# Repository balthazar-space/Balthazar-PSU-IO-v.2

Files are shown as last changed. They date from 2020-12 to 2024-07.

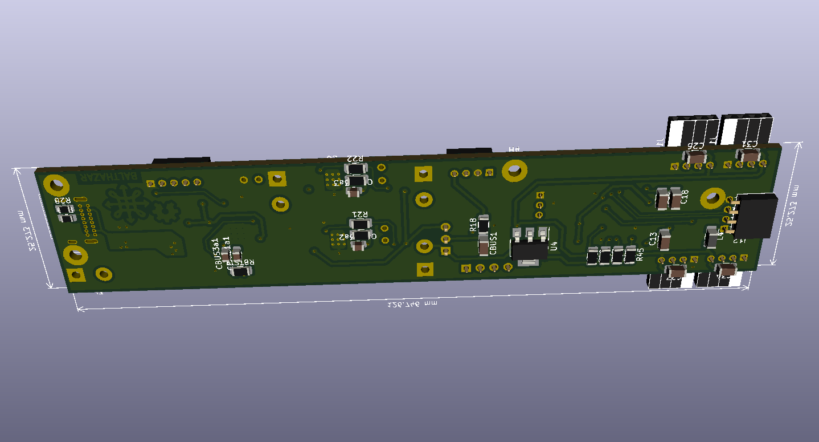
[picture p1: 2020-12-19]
images/BalthazarPSU2-4.png

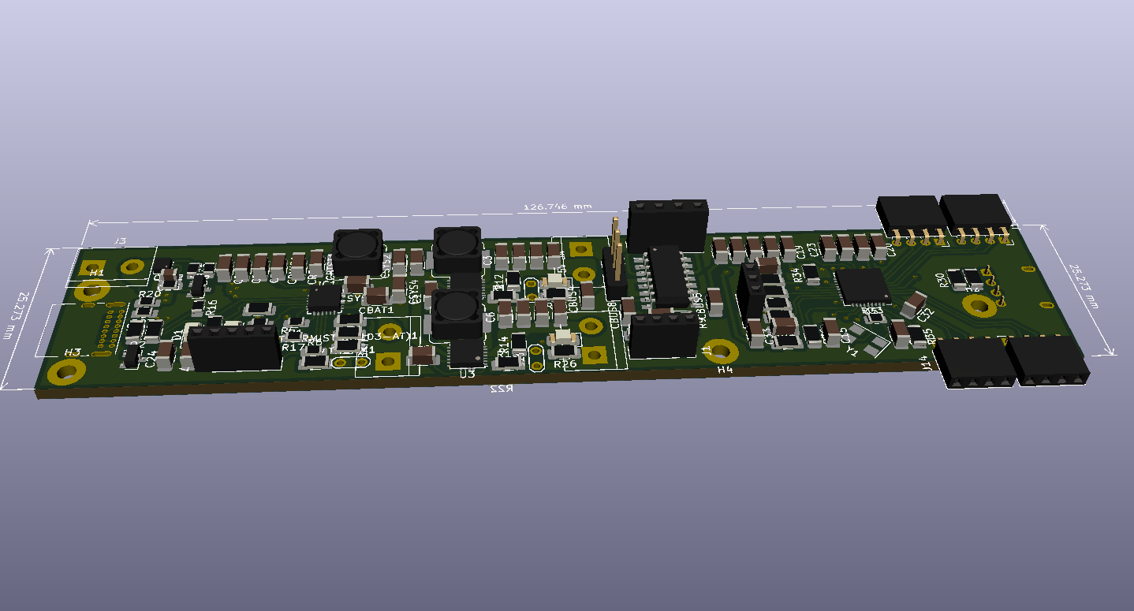
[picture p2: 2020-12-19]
images/BalthazarPSU2-2.png

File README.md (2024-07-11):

# Balthazar

Open-hardware laptop computer modules description and concept.

These are electronic schematic modules as presented at https://balthazar.space/wiki/Balthazar with the main aim for team access. See the [main repository](https://github.com/balthazar-space/balthazar) for other designs.

# balthazar PSU/IO v.2

Module BalthazarPSU2 is a combined battery charger, buck-boost coverter, stereo power amplifier and usb 2.0 hub. A somehow revised version of BalthazarPSU module, this one has an added usb 2.0 hub based on Microchip USB2514B which was much more readily available in Europe than GL3520 chip.
We also work on USB 3.0 - due to the chip shortage/availability - we now have to wait.

KiCad 5.1.5 files.

## License

All resources except the keyboard firmware - which is licensed with with GPLv3 or later - licensed under the CERN Open Hardware Licence CERN-OHL W V.2.0

Version 2.0 of the CERN-OHL introduces three variants of the licence – strongly (S) reciprocal, weakly (W) reciprocal and permissive (P) – which aim to address specific constraints caused by different collaboration models currently used in open-hardware projects. 

The first two variants mean that if any product is made using an open hardware design, the design of that product, including any improvements or modifications, should be made available under the same licence as that of the original product. Permissive licences do not impose this condition.

See the [LICENSE.md](./LICENSE.md) file for more information.

## Funding

This project is funded through the [NGI Zero Entrust Fund](https://nlnet.nl/entrust), a fund
established by [NLnet](https://nlnet.nl) with financial support from the European Commission's
[Next Generation Internet](https://ngi.eu) program. Learn more on the [NLnet project page](https://nlnet.nl/project/Balthazar-Casing/).

[NLNet foundation logo](https://nlnet.nl)
[NGI0 Entrust Logo](https://nlnet.nl/entrust)

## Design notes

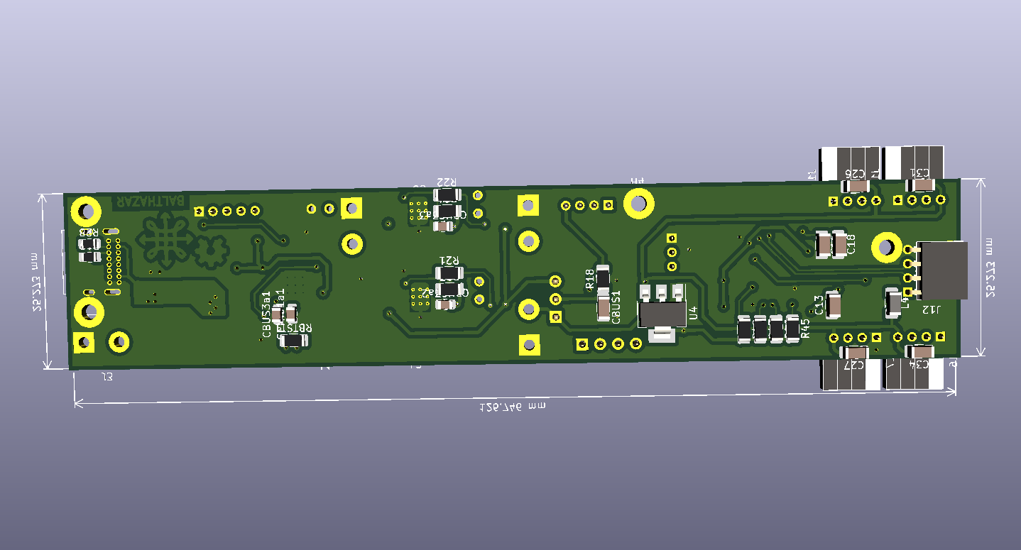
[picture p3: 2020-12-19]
images/BalthazarPSU2-5.png

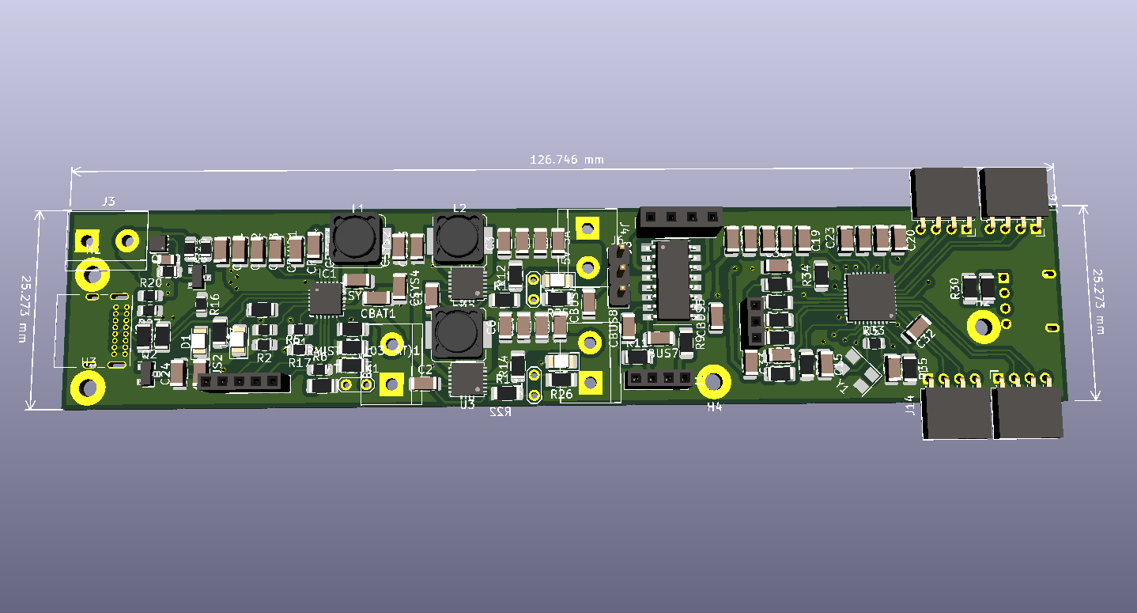
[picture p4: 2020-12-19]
images/BalthazarPSU2-1.png

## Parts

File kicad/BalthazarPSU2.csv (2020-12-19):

Id | Designator | Package | Quantity | Designation | Supplier and ref
1 | REF** | OSHW-Logo_Copper | 1 | OSHW-Logo_Copper
2 | G*** | BALTHAZARlogo150 | 1 | LOGO
3 | U2,U3 | WSON-14-1EP_4.0x4.0mm_P0.5mm_EP2.6x2.6mmThermalPads | 2 | TPS63020
4 | CPSU2,CPSU1,CBTST1,CBUS1,CBUS2,CBUS3,CBUS4,CBUS5,CBUS8,CREGN1,C16,C21 | C_1206_3216Metric | 12 | 1uF
5 | CSYS3,CSYS4,CBAT1,CPMID1,CSYS1,CSYS2,C12,C22,C29,C26,C27,C31,C34 | C_1206_3216Metric | 13 | 10uF
6 | R12,R14,R23,R24 | R_1206_3216Metric | 4 | 1M
7 | R13,R15 | R_1206_3216Metric | 2 | 180K
8 | RBTST1 | R_1206_3216Metric | 1 | R
9 | C8,C9,C3,C4,C10,C5,C7,C6 | C_1206_3216Metric | 8 | 22uF
10 | C1,C2,CBUS7,C11,C17,C18,C19,C23,C28,C30,C32,C33,C13,C20,C24 | C_1206_3216Metric | 15 | 0.1uF
11 | D1,D2,D4,D5 | LED_1206_3216Metric | 4 | Led
12 | R4,R5,R8,R9,R11,R21,R22 | R_1206_3216Metric | 7 | 2K2
13 | R7 | R_1206_3216Metric | 1 | 265
14 | R10 | R_1206_3216Metric | 1 | 6K8
15 | THERMISTOR(103-AT)1,R18,R43,R44,R45,R46,R47,R48 | R_1206_3216Metric | 8 | 10K
16 | IC1 | QFN-24-1EP_4x4mm_P0.5mm_EP2.7x2.7mm_ThermalVias | 1 | BQ24193
17 | U1 | SOP-16_4.4x10.4mm_P1.27mm | 1 | PAM8403-SOP16
18 | THERM1 | TestPoint_2Pads_Pitch2.54mm_Drill0.8mm | 1 | thermistor
19 | J10,J11 | TestPoint_2Pads_Pitch2.54mm_Drill0.8mm | 2 | 3.3V/5V
20 | R25,R26 | R_1206_3216Metric | 2 | 270K
21 | BATT1 | TerminalBlock_bornier-2_P5.08mm | 1 | 1s LiPo
22 | J8 | TerminalBlock_bornier-2_P5.08mm | 1 | 5V 3A
23 | J9 | TerminalBlock_bornier-2_P5.08mm | 1 | 3.3V 4A
24 | CBUS3a1,CBUS3a2,CBUS3a3,CPMID1a1 | C_0805_2012Metric | 4 | 0.1uF
25 | J2 | USB_C_Receptacle_GCT_USB4085 | 1 | USB_C_Receptacle_USB2.0
26 | L1 | L_Bourns_SRP7028A_7.3x6.6mm | 1 | 2.2uH 4A
27 | L2,L3 | L_Bourns_SRP7028A_7.3x6.6mm | 2 | 1.5uH 4A
28 | J3 | TerminalBlock_bornier-2_P5.08mm | 1 | 5-15V / 3-5A
29 | C14,C15 | C_1206_3216Metric | 2 | 20pF
30 | R29,R30,R31,R32,R34,R36,R37 | R_1206_3216Metric | 7 | 100K
31 | R35 | R_1206_3216Metric | 1 | 12K
32 | U4 | SOT-223-3_TabPin2 | 1 | AMS1117-3.3
33 | U5 | QFN-36-1EP_6x6mm_P0.5mm_EP3.7x3.7mm | 1 | USB2514B_Bi
34 | J13 | USB_Micro-B_Molex-Balthazar | 1 | USB_B_Micro
35 | R33 | R_0805_2012Metric | 1 | 1M
36 | C25 | C_0805_2012Metric | 1 | 1nF
37 | Q1 | Texas_DQK | 1 | CSD25310Q2
38 | Q2,Q3 | SOT-23 | 2 | BSS138
39 | R19,R27 | R_0805_2012Metric_Pad1.15x1.40mm_HandSolder | 2 | 5K1
40 | R20,R28 | R_0805_2012Metric_Pad1.15x1.40mm_HandSolder | 2 | 56K
41 | R40 | R_0805_2012Metric_Pad1.15x1.40mm_HandSolder | 1 | 262K
42 | R41 | R_0805_2012Metric_Pad1.15x1.40mm_HandSolder | 1 | 100K
43 | R42,R1,R2,R3,R6,R16,R17 | R_0805_2012Metric_Pad1.15x1.40mm_HandSolder | 7 | 10K
44 | J12,J14,J15,J16,J17 | PinSocket_1x04_P2.00mm_Horizontal | 5 | Conn_01x04_USB
45 | J4 | PinSocket_1x04_P2.54mm_Vertical | 1 | AudioOUT
46 | J7 | PinSocket_1x05_P2.00mm_Vertical | 1 | uC host / Atmel
47 | J1 | PinSocket_1x04_P2.00mm_Vertical | 1 | AudioIN
48 | R38 | R_1206_3216Metric | 1 | 120K
49 | R39 | R_1206_3216Metric | 1 | 49K9
50 | Y1 | Crystal_SMD_5032-4Pin_5.0x3.2mm | 1 | Crystal_GND24
51 | L4 | L_1206_3216Metric_Pad1.42x1.75mm_HandSolder | 1 | L_Core_Ferrite_Small
52 | J5 | PinSocket_1x03_P2.00mm_Vertical | 1 | uC host / Atmel
53 | J6 | PinHeader_1x03_P2.54mm_Vertical | 1 | Conn_01x03_Male
54 | H1,H2,H3,H4 | MountingHole_2.2mm_M2_Pad | 4 | MountingHole_Pad

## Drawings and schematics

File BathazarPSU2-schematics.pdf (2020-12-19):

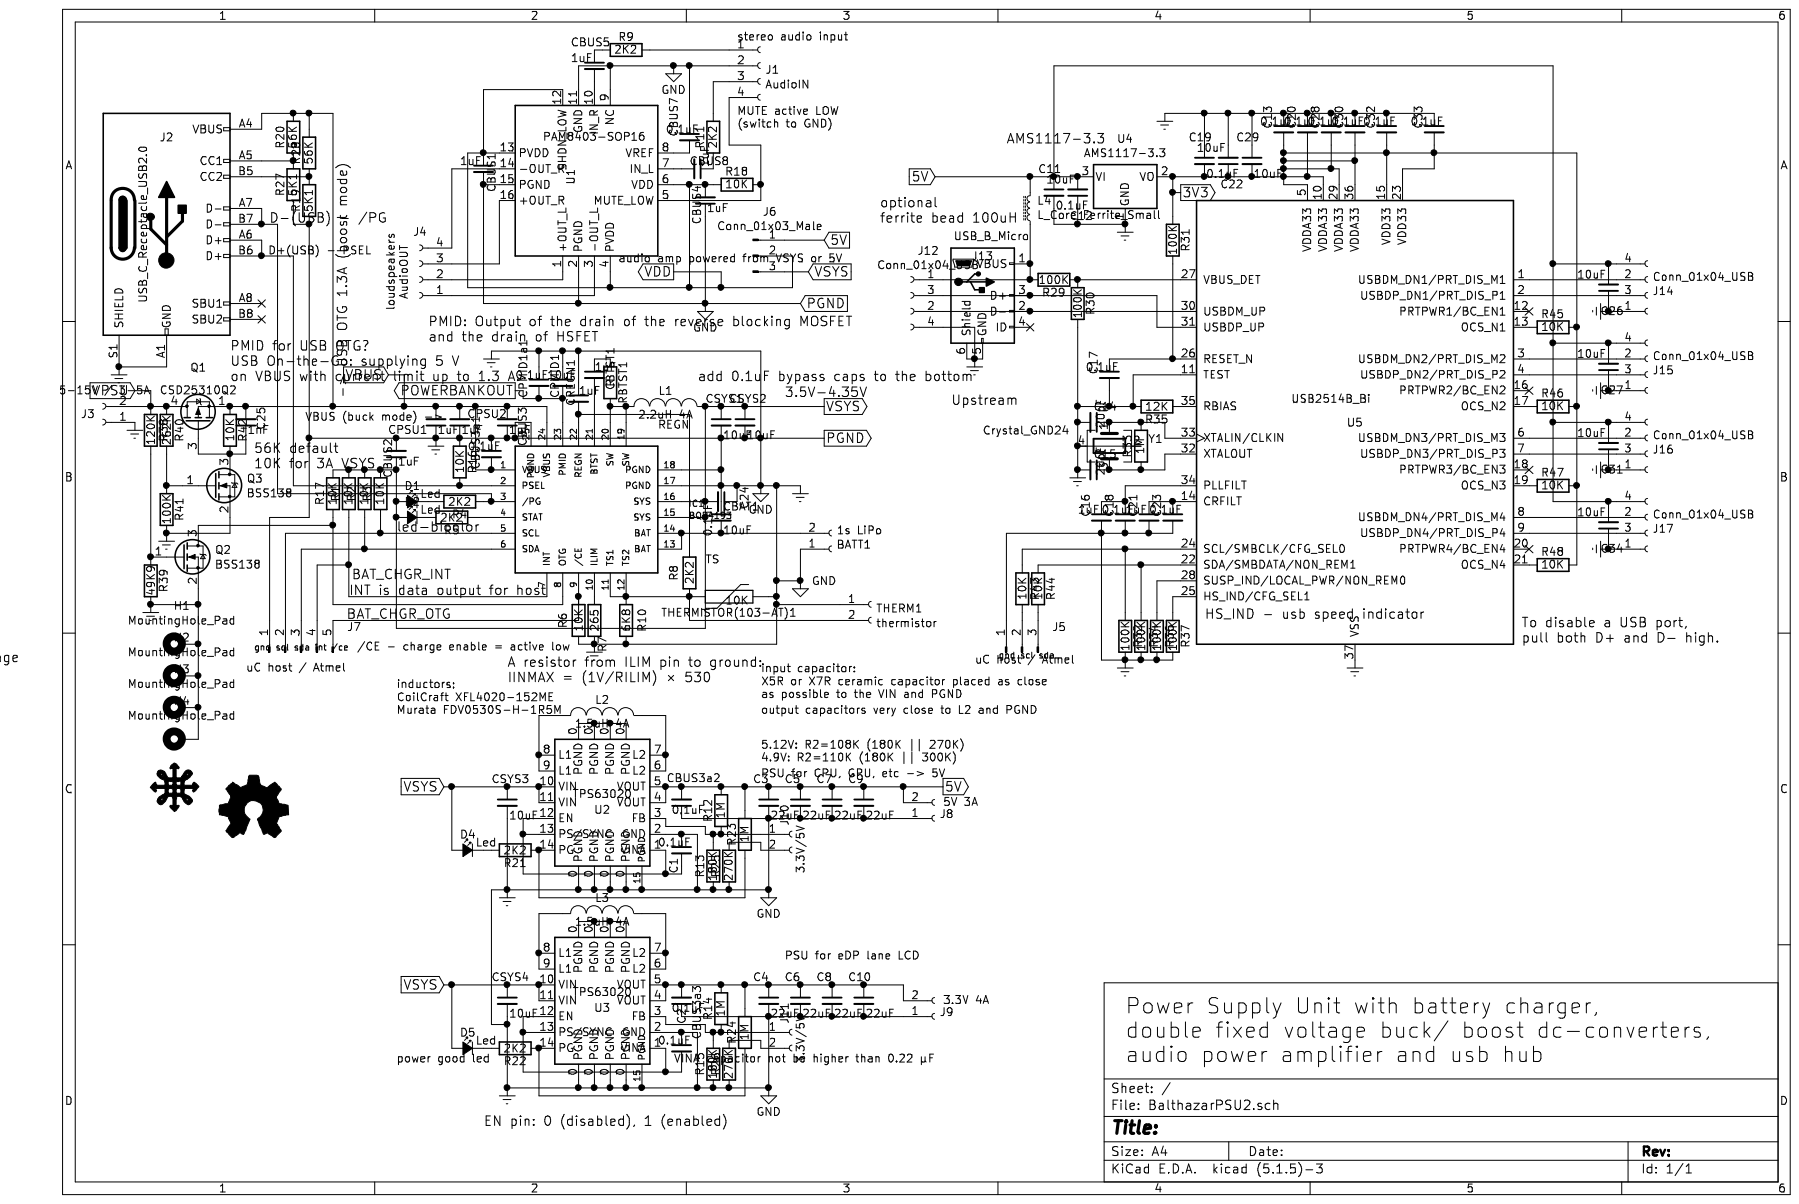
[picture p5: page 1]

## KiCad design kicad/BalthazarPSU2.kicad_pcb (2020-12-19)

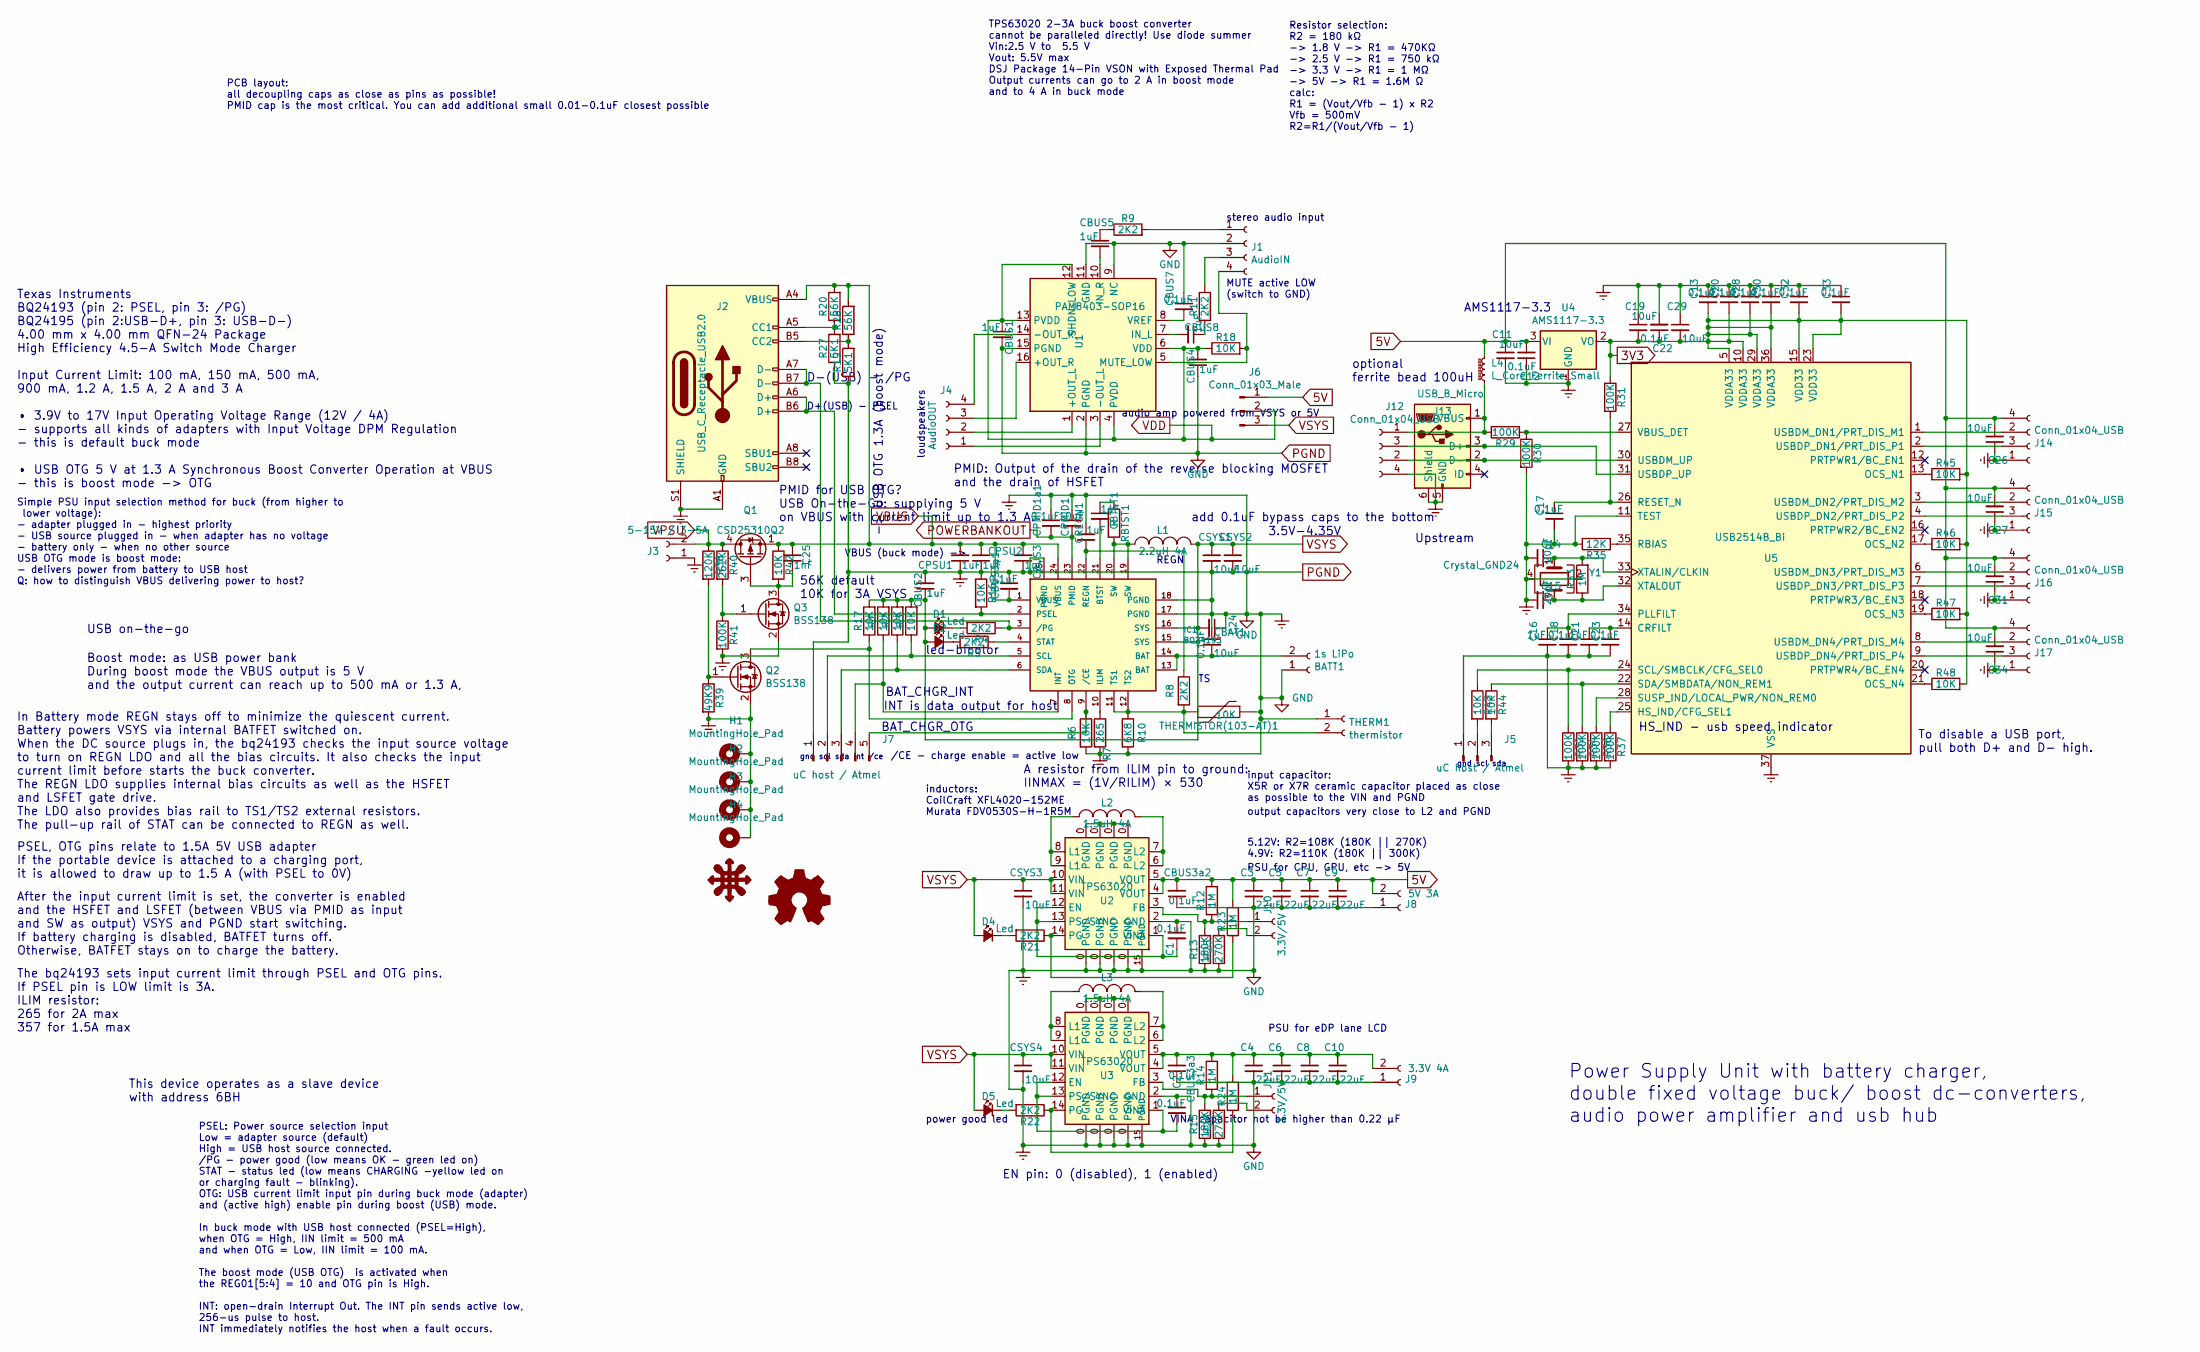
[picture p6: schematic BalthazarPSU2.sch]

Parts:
BATT1: 1s LiPo; TerminalBlock_bornier-2_P5.08mm
C1, C2, C11, C13, C17, C18, C19, C20, C23, C24, C28, C30, C32, C33: 0.1uF; C_1206_3216Metric
C3, C4, C5, C6, C7, C8, C9, C10: 22uF; C_1206_3216Metric
C12, C22, C26, C27, C29, C31, C34: 10uF; C_1206_3216Metric
C14, C15: 20pF; C_1206_3216Metric
C16, C21: 1uF; C_1206_3216Metric
C25: 1nF; C_0805_2012Metric
CBAT1: 10uF; C_1206_3216Metric
CBTST1: 1uF; C_1206_3216Metric
CBUS1, CBUS2, CBUS3, CBUS4, CBUS5, CBUS8: 1uF; C_1206_3216Metric
CBUS3a1, CBUS3a2, CBUS3a3: 0.1uF; C_0805_2012Metric
CBUS7: 0.1uF; C_1206_3216Metric
CPMID1: 10uF; C_1206_3216Metric
CPMID1a1: 0.1uF; C_0805_2012Metric
CPSU1, CPSU2: 1uF; C_1206_3216Metric
CREGN1: 1uF; C_1206_3216Metric
CSYS1, CSYS2, CSYS3, CSYS4: 10uF; C_1206_3216Metric
D1, D2, D4, D5: Led; LED_1206_3216Metric
H1, H2, H3, H4: MountingHole_Pad; MountingHole_2.2mm_M2_Pad
IC1: BQ24193; QFN-24-1EP_4x4mm_P0.5mm_EP2.7x2.7mm_ThermalVias
J1: AudioIN; PinSocket_1x04_P2.00mm_Vertical
J2: USB_C_Receptacle_USB2.0; USB_C_Receptacle_GCT_USB4085
J3: 5-15V / 3-5A; TerminalBlock_bornier-2_P5.08mm
J4: AudioOUT; PinSocket_1x04_P2.54mm_Vertical
J5: uC host / Atmel; PinSocket_1x03_P2.00mm_Vertical
J6: Conn_01x03_Male; PinHeader_1x03_P2.54mm_Vertical
J7: uC host / Atmel; PinSocket_1x05_P2.00mm_Vertical
J8: 5V 3A; TerminalBlock_bornier-2_P5.08mm
J9: 3.3V 4A; TerminalBlock_bornier-2_P5.08mm
J10, J11: 3.3V/5V; TestPoint_2Pads_Pitch2.54mm_Drill0.8mm
J12, J14, J15, J16, J17: Conn_01x04_USB; PinSocket_1x04_P2.00mm_Horizontal
J13: USB_B_Micro; USB_Micro-B_Molex-Balthazar
L1: 2.2uH 4A; L_Bourns_SRP7028A_7.3x6.6mm
L2, L3: 1.5uH 4A; L_Bourns_SRP7028A_7.3x6.6mm
L4: L_Core_Ferrite_Small; L_1206_3216Metric_Pad1.42x1.75mm_HandSolder
Q1: CSD25310Q2; Texas_DQK
Q2, Q3: BSS138; SOT-23
R1, R2, R3, R6, R16, R17, R42: 10K; R_0805_2012Metric_Pad1.15x1.40mm_HandSolder
R4, R5, R8, R9, R11, R21, R22: 2K2; R_1206_3216Metric
R7: 265; R_1206_3216Metric
R10: 6K8; R_1206_3216Metric
R12, R14, R23, R24: 1M; R_1206_3216Metric
R13, R15: 180K; R_1206_3216Metric
R18, R43, R44, R45, R46, R47, R48: 10K; R_1206_3216Metric
R19, R27: 5K1; R_0805_2012Metric_Pad1.15x1.40mm_HandSolder
R20, R28: 56K; R_0805_2012Metric_Pad1.15x1.40mm_HandSolder
R25, R26: 270K; R_1206_3216Metric
R29, R30, R31, R32, R34, R36, R37: 100K; R_1206_3216Metric
R33: 1M; R_0805_2012Metric
R35: 12K; R_1206_3216Metric
R38: 120K; R_1206_3216Metric
R39: 49K9; R_1206_3216Metric
R40: 262K; R_0805_2012Metric_Pad1.15x1.40mm_HandSolder
R41: 100K; R_0805_2012Metric_Pad1.15x1.40mm_HandSolder
RBTST1: R; R_1206_3216Metric
THERM1: thermistor; TestPoint_2Pads_Pitch2.54mm_Drill0.8mm
THERMISTOR(103-AT)1: 10K; R_1206_3216Metric
U1: PAM8403-SOP16; SOP-16_4.4x10.4mm_P1.27mm
U2, U3: TPS63020; WSON-14-1EP_4.0x4.0mm_P0.5mm_EP2.6x2.6mmThermalPads
U4: AMS1117-3.3; SOT-223-3_TabPin2
U5: USB2514B_Bi; QFN-36-1EP_6x6mm_P0.5mm_EP3.7x3.7mm
Y1: Crystal_GND24; Crystal_SMD_5032-4Pin_5.0x3.2mm

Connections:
3V3: C13.2, C19.2, C20.2, C22.1, C28.2, C29.2, C30.2, C32.2, C33.2, R31.1, R45.2, R46.2, R47.2, R48.2, U4.2 (VO), U5.5 (VDDA33), U5.10 (VDDA33), U5.15 (VDD33), U5.23 (VDD33), U5.29 (VDDA33), U5.36 (VDDA33)
5V: C3.1, C5.1, C7.1, C9.1, C11.1, C12.2, C26.2, C27.2, C31.2, C34.2, CBUS3a2.2, J6.1, J8.2, J14.4, J15.4, J16.4, J17.4, L4.2, R12.2, R23.2, U2.4 (VOUT), U2.5 (VOUT), U4.3 (VI)
unnamed: BATT1.2, CBAT1.2, IC1.13 (BAT), IC1.14 (BAT)
unnamed: C1.2, U2.1 (VINA), U2.12 (EN), U2.13 (PS/SYNC)
unnamed: C2.2, U3.1 (VINA), U3.12 (EN), U3.13 (PS/SYNC)
unnamed: C4.1, C6.1, C8.1, C10.1, CBUS3a3.2, J9.2, R14.2, R24.2, U3.4 (VOUT), U3.5 (VOUT)
unnamed: C14.1, R33.2, U5.33 (XTALIN/CLKIN), Y1.1
unnamed: C15.1, R33.1, U5.32 (XTALOUT), Y1.3
unnamed: C16.1, C18.1, U5.34 (PLLFILT)
unnamed: C17.1, R31.2, U5.26 (RESET_N)
unnamed: C21.1, C23.1, U5.14 (CRFILT)
unnamed: C25.1, Q1.3 (G), Q3.3 (D), R42.2
unnamed: CBTST1.1, RBTST1.1
unnamed: CBTST1.2, IC1.21 (BTST)
unnamed: CBUS5.1, R9.1
unnamed: CBUS5.2, U1.10 (IN_R)
unnamed: CBUS7.2, U1.8 (VREF)
unnamed: CBUS8.1, R11.1
unnamed: CBUS8.2, U1.7 (IN_L)
unnamed: CREGN1.2, IC1.22 (REGN), R8.1
unnamed: D1.2 (C), R4.2
unnamed: D2.2 (C), R5.2
unnamed: D4.2 (C), R21.2
unnamed: D5.2 (C), R22.2
unnamed: IC1.2 (PSEL), J2.A6 (D+), J2.B6 (D+), R16.2
unnamed: IC1.3 (/PG), J2.A7 (D-), J2.B7 (D-), R4.1
unnamed: IC1.4 (STAT), R5.1
unnamed: IC1.5 (SCL), J7.2, R3.1
unnamed: IC1.6 (SDA), J7.3, R2.1
unnamed: IC1.7 (INT), J7.4, R1.1
unnamed: IC1.8 (OTG), Q2.3 (D), R17.1
unnamed: IC1.9 (/CE), J7.5, R6.1
unnamed: IC1.10 (ILIM), R7.1
unnamed: IC1.11 (TS1), IC1.12 (TS2), R8.2, R10.1, THERM1.2, THERMISTOR(103-AT)1.2
unnamed: IC1.19 (SW), IC1.20 (SW), L1.1, RBTST1.2
unnamed: J1.1, R9.2
unnamed: J1.3, R11.2
unnamed: J1.4, R18.2, U1.5 (MUTE_LOW)
unnamed: J2.A5 (CC1), R20.1, R27.2
unnamed: J2.B5 (CC2), R19.2, R28.1
unnamed: J4.1, U1.3 (-OUT_L)
unnamed: J4.2, U1.1 (+OUT_L)
unnamed: J4.3, U1.16 (+OUT_R)
unnamed: J4.4, U1.14 (-OUT_R)
unnamed: J5.2, R43.2
unnamed: J5.3, R44.2
unnamed: J10.1, R12.1, R13.2, U2.3 (FB)
unnamed: J10.2, R25.2
unnamed: J11.1, R14.1, R15.2, U3.3 (FB)
unnamed: J11.2, R26.2
unnamed: J12.1, J13.1 (VBUS), L4.1, R29.2
unnamed: J12.2, J13.2 (D-), U5.30 (USBDM_UP)
unnamed: J12.3, J13.3 (D+), U5.31 (USBDP_UP)
unnamed: J14.2, U5.1 (USBDM_DN1/PRT_DIS_M1)
unnamed: J14.3, U5.2 (USBDP_DN1/PRT_DIS_P1)
unnamed: J15.2, U5.3 (USBDM_DN2/PRT_DIS_M2)
unnamed: J15.3, U5.4 (USBDP_DN2/PRT_DIS_P2)
unnamed: J16.2, U5.6 (USBDM_DN3/PRT_DIS_M3)
unnamed: J16.3, U5.7 (USBDP_DN3/PRT_DIS_P3)
unnamed: J17.2, U5.8 (USBDM_DN4/PRT_DIS_M4)
unnamed: J17.3, U5.9 (USBDP_DN4/PRT_DIS_P4)
unnamed: L2.1, U2.8 (L1), U2.9 (L1)
unnamed: L2.2, U2.6 (L2), U2.7 (L2)
unnamed: L3.1, U3.8 (L1), U3.9 (L1)
unnamed: L3.2, U3.6 (L2), U3.7 (L2)
unnamed: Q2.1 (G), R38.2, R39.1
unnamed: Q3.1 (G), R40.2, R41.1
unnamed: R21.1, R23.1, U2.14 (PG)
unnamed: R22.1, R24.1, U3.14 (PG)
unnamed: R29.1, R30.1, U5.27 (VBUS_DET)
unnamed: R32.1, R43.1, U5.24 (SCL/SMBCLK/CFG_SEL0)
unnamed: R34.1, R44.1, U5.22 (SDA/SMBDATA/NON_REM1)
unnamed: R35.1, U5.35 (RBIAS)
unnamed: R36.1, U5.28 (SUSP_IND/LOCAL_PWR/NON_REM0)
unnamed: R37.1, U5.25 (HS_IND/CFG_SEL1)
unnamed: R45.1, U5.13 (OCS_N1)
unnamed: R46.1, U5.17 (OCS_N2)
unnamed: R47.1, U5.19 (OCS_N3)
unnamed: R48.1, U5.21 (OCS_N4)
PGND: BATT1.1, C1.1, C2.1, C3.2, C4.2, C5.2, C6.2, C7.2, C8.2, C9.2, C10.2, C11.2, C12.1, C13.1, C14.2, C15.2, C16.2, C17.2, C18.2, C19.1, C20.1, C21.2, C22.2, C23.2, C24.1, C26.1, C27.1, C28.1, C29.1, C30.1, C31.1, C32.1, C33.1, C34.1, CBAT1.1, CBUS1.2, CBUS2.2, CBUS3.1, CBUS3a1.1, CBUS3a2.1, CBUS3a3.1, CBUS4.1, CBUS7.1, CPMID1.1, CPMID1a1.1, CPSU1.1, CPSU2.1, CREGN1.1, CSYS1.2, CSYS2.2, CSYS3.2, CSYS4.2, H1.1, H2.1, H3.1, H4.1, IC1.17 (PGND), IC1.18 (PGND), IC1.25 (PGND), J1.2, J2.A1 (GND), J2.A12 (GND), J2.B1 (GND), J2.B12 (GND), J2.S1 (SHIELD), J3.1, J5.1, J7.1, J8.1, J9.1, J12.4, J13.5 (GND), J13.6 (Shield), J14.1, J15.1, J16.1, J17.1, Q2.2 (S), Q3.2 (S), R6.2, R7.2, R10.2, R13.1, R15.1, R16.1, R19.1, R25.1, R26.1, R27.1, R30.2, R32.2, R34.2, R35.2, R36.2, R37.2, R39.2, R41.2, THERM1.1, THERMISTOR(103-AT)1.1, U1.2 (PGND), U1.9 (NC), U1.11 (GND), U1.15 (PGND), U2.0 (PGND), U2.2 (GND), U2.15 (PGND), U3.0 (PGND), U3.2 (GND), U3.15 (PGND), U4.1 (GND), U5.11 (TEST), U5.37 (VSS), Y1.2, Y1.4
POWERBANKOUT: CPMID1.2, CPMID1a1.2, IC1.23 (PMID)
VBUS: C25.2, CBUS3.2, CBUS3a1.2, CPSU1.2, CPSU2.2, IC1.1 (VBUS), IC1.24 (VBUS), J2.A4 (VBUS), J2.A9 (VBUS), J2.B4 (VBUS), J2.B9 (VBUS), Q1.1 (S), Q1.2 (S), Q1.5 (S), Q1.6 (S), Q1.8 (S), R20.2, R28.2, R42.1
VDD: CBUS1.1, CBUS4.2, J6.2, R18.1, U1.4 (PVDD), U1.6 (VDD), U1.12 (SHDN_LOW), U1.13 (PVDD)
VPSU: J3.2, Q1.4 (D), Q1.7 (D), R38.1, R40.1
VSYS: C24.2, CBUS2.1, CSYS1.1, CSYS2.1, CSYS3.1, CSYS4.1, D1.1 (A), D2.1 (A), D4.1 (A), D5.1 (A), IC1.15 (SYS), IC1.16 (SYS), J6.3, L1.2, R1.2, R2.2, R3.2, R17.2, U2.10 (VIN), U2.11 (VIN), U3.10 (VIN), U3.11 (VIN)

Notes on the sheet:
3.5V-4.35V
USB on-the-go
led-bicolor
BAT_CHGR_INT
BAT_CHGR_OTG
INT is data output for host
Texas Instruments BQ24193 (pin 2: PSEL, pin 3: /PG) BQ24195 (pin 2:USB-D+, pin 3: USB-D-) 4.00 mm x 4.00 mm QFN-24 Package High Efficiency 4.5-A Switch Mode Charger Input Current Limit: 100 mA, 150 mA, 500 mA, 900 mA, 1.2 A, 1.5 A, 2 A and 3 A • 3.9V to 17V Input Operating Voltage Range (12V / 4A) 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
PSEL, OTG pins relate to 1.5A 5V USB adapter If the portable device is attached to a charging port, it is allowed to draw up to 1.5 A (with PSEL to 0V)
In Battery mode REGN stays off to minimize the quiescent current. Battery powers VSYS via internal BATFET switched on. When the DC source plugs in, the bq24193 checks the input source voltage to turn on REGN LDO and all the bias circuits. It also checks the input current limit before starts the buc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
The bq24193 sets input current limit through PSEL and OTG pins. If PSEL pin is LOW limit is 3A. ILIM resistor: 265 for 2A max 357 for 1.5A max
After the input current limit is set, the converter is enabled and the HSFET and LSFET (between VBUS via PMID as input and SW as output) VSYS and PGND start switching. If battery charging is disabled, BATFET turns off. Otherwise, BATFET stays on to charge the battery.
PSU for CPU, GPU, etc -> 5V
TPS63020 2-3A buck boost converter cannot be paralleled directly! Use diode summer Vin:2.5 V to 5.5 V Vout: 5.5V max DSJ Package 14-Pin VSON with Exposed Thermal Pad Output currents can go to 2 A in boost mode and to 4 A in buck mode
inductors: CoilCraft XFL4020-152ME Murata FDV0530S-H-1R5M
Resistor selection: R2 = 180 kΩ -> 1.8 V -> R1 = 470KΩ -> 2.5 V -> R1 = 750 kΩ -> 3.3 V -> R1 = 1 MΩ -> 5V -> R1 = 1.6M Ω calc: R1 = (Vout/Vfb - 1) x R2 Vfb = 500mV R2=R1/(Vout/Vfb - 1)
REGN
stereo audio input
loudspeakers
MUTE active LOW (switch to GND)
D+(USB) - PSEL
Power Supply Unit with battery charger, double fixed voltage buck/ boost dc-converters, audio power amplifier and usb hub
PCB layout: all decoupling caps as close as pins as possible! PMID cap is the most critical. You can add additional small 0.01-0.1uF closest possible
PSU for eDP lane LCD
audio amp powered from VSYS or 5V
VBUS (buck mode) ->
Simple PSU input selection method for buck (from higher to lower voltage): - adapter plugged in - highest priority - USB source plugged in - when adapter has no voltage - battery only - when no other source USB OTG mode is boost mode: - delivers power from battery to USB host Q: how to distinguish 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
output capacitors very close to L2 and PGND
input capacitor: X5R or X7R ceramic capacitor placed as close as possible to the VIN and PGND
VINA capacitor not be higher than 0.22 μF
power good led
5.12V: R2=108K (180K || 270K) 4.9V: R2=110K (180K || 300K)
Boost mode: as USB power bank During boost mode the VBUS output is 5 V and the output current can reach up to 500 mA or 1.3 A,
gnd scl sda int /ce
add 0.1uF bypass caps to the bottom
EN pin: 0 (disabled), 1 (enabled)
/CE - charge enable = active low
56K default 10K for 3A
D-(USB) - /PG
HS_IND - usb speed indicator
Upstream

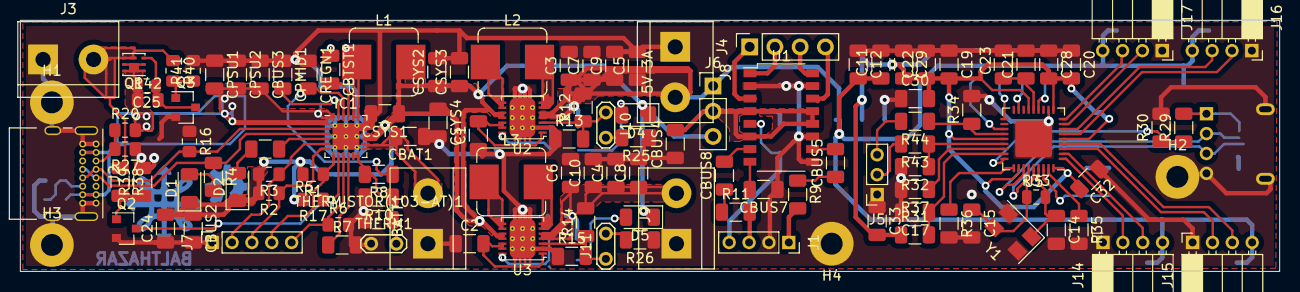
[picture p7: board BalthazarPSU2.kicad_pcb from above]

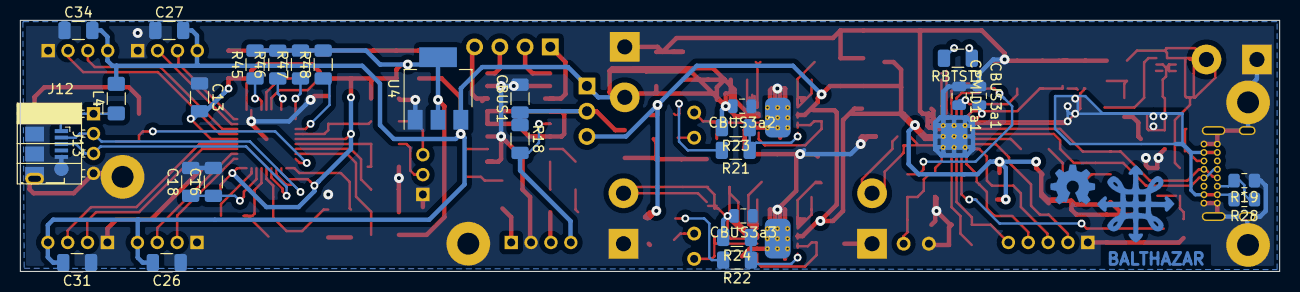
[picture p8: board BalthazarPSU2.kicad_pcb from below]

Board: 2 copper layers, 126.7 x 25.3 mm, 146 parts (28 on the bottom side), 85 nets.
